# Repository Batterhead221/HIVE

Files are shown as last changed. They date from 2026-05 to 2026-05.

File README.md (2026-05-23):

# HIVE

<p align="center">
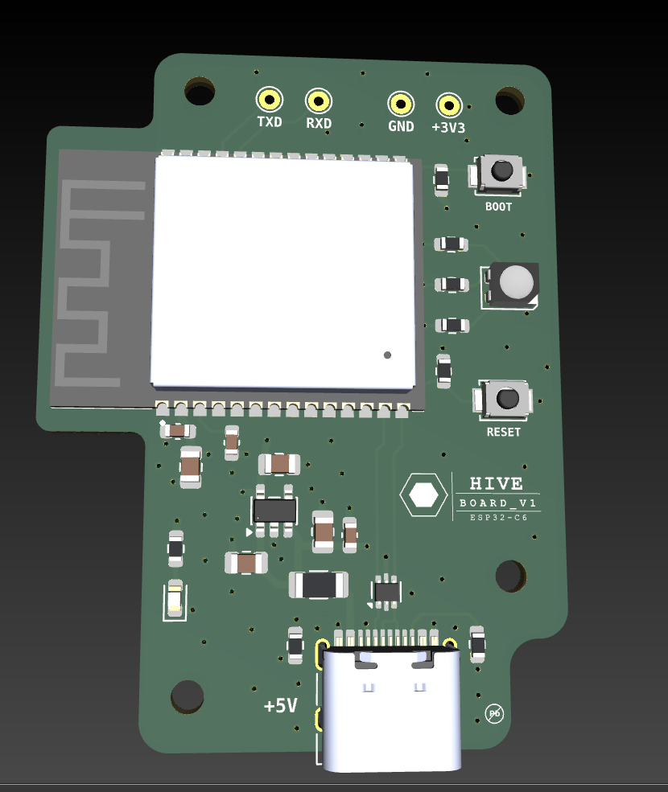
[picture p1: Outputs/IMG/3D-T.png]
HIVE top 3D board render
  
</p>

<p align="center">
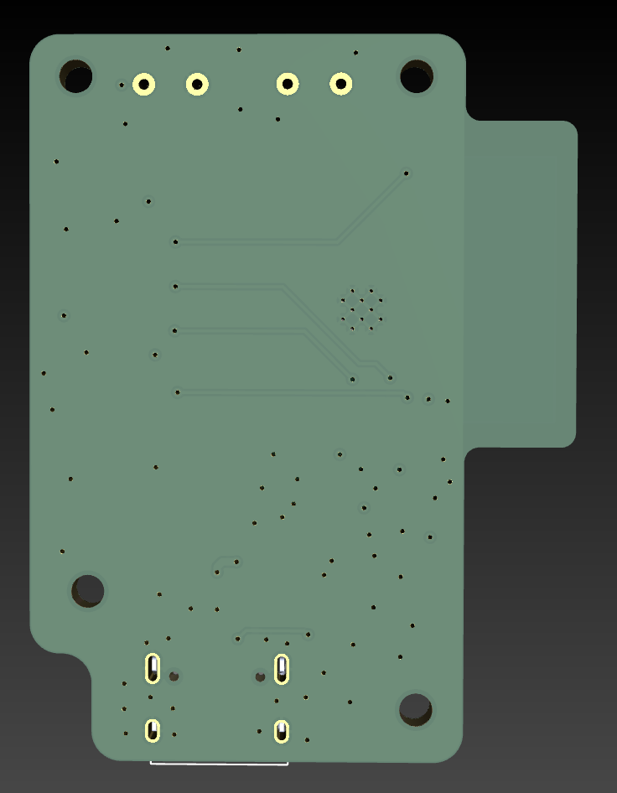
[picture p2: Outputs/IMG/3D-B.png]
HIVE bottom 3D board render
  
</p>

ESP32-C6 gateway board for receiving GRUNT outlet/circuit heartbeat packets.

HIVE is the central receiver in the HIVE + GRUNT monitoring system. It listens for ESP-NOW heartbeat packets from one or more GRUNT sender nodes and reports whether each monitored outlet/circuit is ON, OFF, or waiting for first heartbeat.

## Project Status

Prototype hardware designed. ESP-NOW proof-of-concept tested with an ESP32-C6 gateway and XIAO ESP32-S3 sender node.

## System Role

```text
GRUNT sender node
    ↓ ESP-NOW heartbeat
HIVE gateway board
    ↓ USB serial
Computer / future dashboard
```

## Hardware

Main parts:

- ESP32-C6-WROOM-1-N8 module
- USB-C power and data
- AP2112K-3.3 voltage regulator
- USBLC6-2P6 USB ESD protection
- BOOT and RESET buttons
- RGB status LED
- Power LED
- UART debug pads
- 4-layer PCB with internal GND plane

## Power

HIVE is powered from USB-C VBUS.

```text
USB-C VBUS → fuse/protection → +5V
+5V → AP2112K-3.3 → +3.3V
+3.3V → ESP32-C6-WROOM-1-N8
```

## USB-C

USB-C is used for both power and native ESP32-C6 USB data.

```text
USB D- → ESP32-C6 GPIO12 / USB_D-
USB D+ → ESP32-C6 GPIO13 / USB_D+
CC1 → 5.1k → GND
CC2 → 5.1k → GND
USB shield → GND
```

## Firmware Behavior

HIVE receives heartbeat packets from GRUNT nodes over ESP-NOW.

Each packet contains:

```cpp
typedef struct {
  char nodeId[16];
  uint32_t counter;
  uint32_t uptimeMs;
} HeartbeatPacket;
```

HIVE tracks the last-seen time for each node.

```text
recent heartbeat → node is ON
timeout expired  → node is OFF / missing
never seen       → node is UNKNOWN
```

## PCB Notes

Recommended layer strategy:

```text
T.SIGNAL → components, USB, local signals
GND      → solid internal GND plane
PWR      → +3.3V pour / power routing
B.SIGNAL → GND pour and slow signals
```

Antenna keepout must block copper on all layers:

- No tracks
- No vias
- No pads
- No zone fills
- No components

## Safety Note

HIVE is a low-voltage USB-powered gateway. It does not connect directly to mains voltage.

## Known Notes

- HIVE is the receiver/gateway board.
- GRUNT is the sender/outlet node.
- ESP-NOW devices must be on the same Wi-Fi channel.
- The ESP32-C6 module antenna keepout is critical for reliable wireless performance.
- UART debug pads are included as a backup even though native USB is used.

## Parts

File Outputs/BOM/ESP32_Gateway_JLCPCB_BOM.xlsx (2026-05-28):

Comment | Designator | Footprint
10U | C1,C2,C4,C7 | C_0805_2012Metric
100N | C3,C5,C6 | C_0603_1608Metric
USBLC6-2P6 | D1 | SOT-666
RBG_LED | D2 | LED_Cree-PLCC4_3.2x2.8mm_CCW
GREEN | D3 | LED_0603_1608Metric
1A | F1 | Fuse_1206_3216Metric
USB_C | J1 | USB_C_Receptacle_HRO_TYPE-C-31-M-12
5K1 | R1,R2 | R_0603
10K | R3,R4 | R_0603
1K | R5,R6,R7,R8 | R_0603
ESP32-C6-WROOM-1-N8 | RF1 | XCVR_ESP32-C6-WROOM-1-N8
RESET | SW1 | SW_SPST_B3U-1000P
BOOT | SW2 | SW_SPST_B3U-1000P
AP2112K-3.3 | U1 | SOT-23-5

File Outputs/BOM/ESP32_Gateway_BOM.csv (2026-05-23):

Id | Designator | Footprint | Quantity | Designation | Supplier and ref
1 | C1, C2, C4, C7 | C_0805_2012Metric | 4 | 10U
2 | C3, C5, C6 | C_0603_1608Metric | 3 | 100N
3 | D1 | SOT-666 | 1 | USBLC6-2P6
4 | D2 | LED_Cree-PLCC4_3.2x2.8mm_CCW | 1 | RBG_LED
5 | D3 | LED_0603_1608Metric | 1 | GREEN
6 | F1 | Fuse_1206_3216Metric | 1 | 1A
7 | J1 | USB_C_Receptacle_HRO_TYPE-C-31-M-12 | 1 | USB_C
8 | R1, R2 | R_0603 | 2 | 5K1
9 | R3, R4 | R_0603 | 2 | 10K
10 | R5, R6, R7, R8 | R_0603 | 4 | 1K
11 | RF1 | XCVR_ESP32-C6-WROOM-1-N8 | 1 | ESP32-C6-WROOM-1-N8
12 | SW1 | SW_SPST_B3U-1000P | 1 | RESET
13 | SW2 | SW_SPST_B3U-1000P | 1 | BOOT
14 | TP1 | TestPoint_THTPad_D1.5mm_Drill0.7mm | 1 | TXD
15 | TP2 | TestPoint_THTPad_D1.5mm_Drill0.7mm | 1 | RXD
16 | TP3 | TestPoint_THTPad_D1.5mm_Drill0.7mm | 1 | GND
17 | TP4 | TestPoint_THTPad_D1.5mm_Drill0.7mm | 1 | +3.3V
18 | U1 | SOT-23-5 | 1 | AP2112K-3.3

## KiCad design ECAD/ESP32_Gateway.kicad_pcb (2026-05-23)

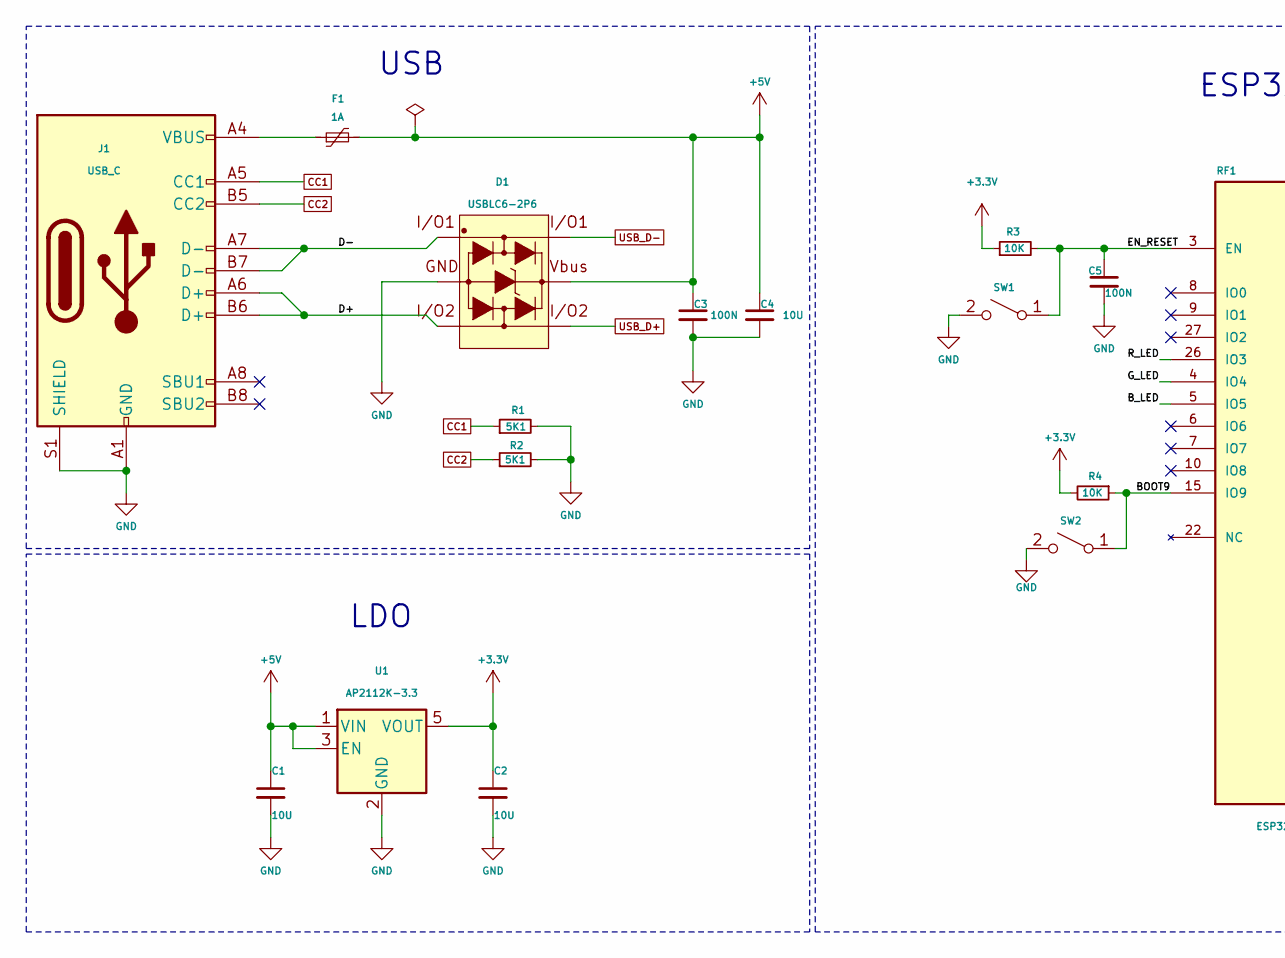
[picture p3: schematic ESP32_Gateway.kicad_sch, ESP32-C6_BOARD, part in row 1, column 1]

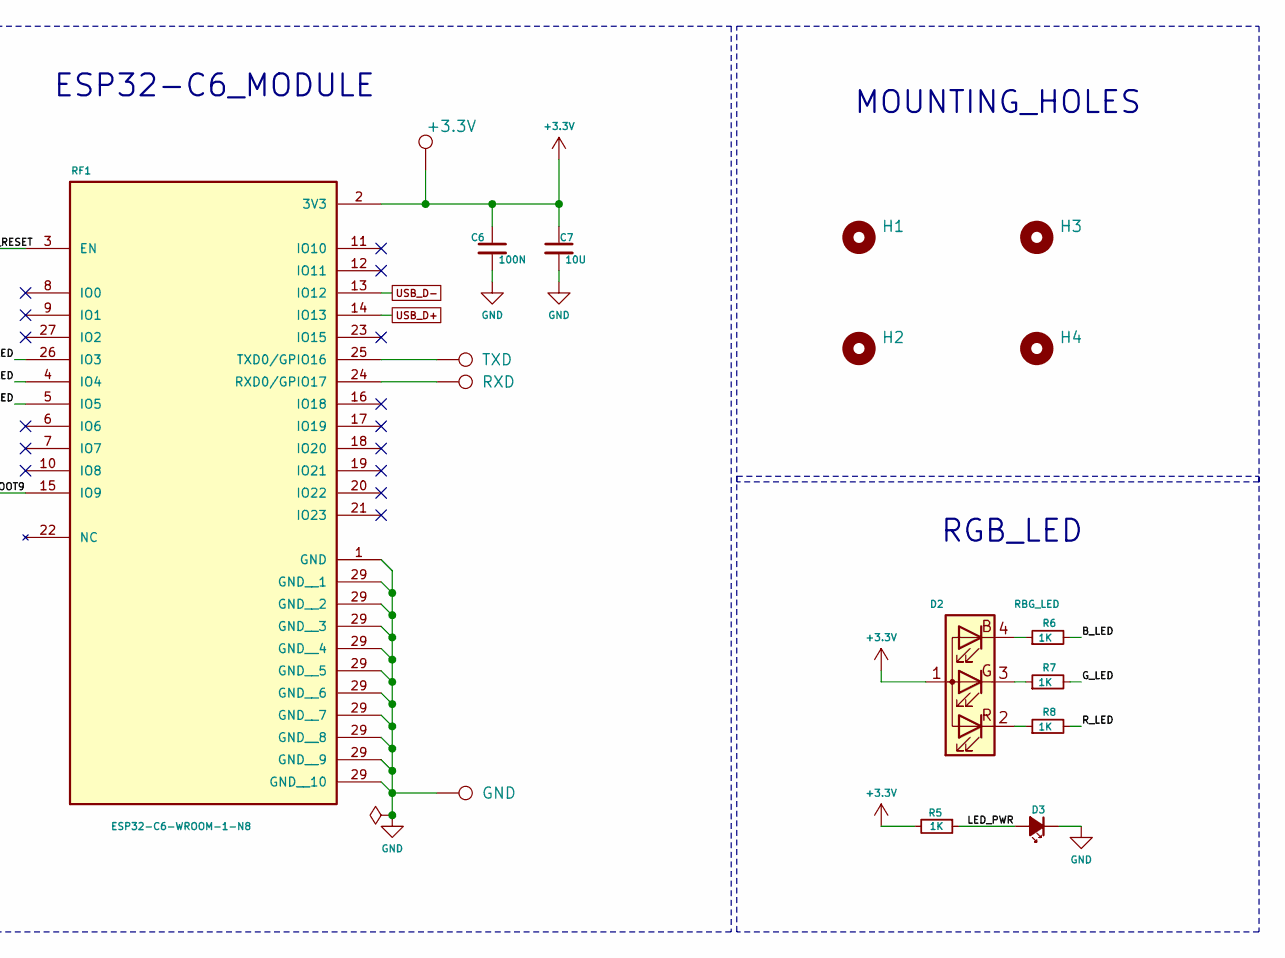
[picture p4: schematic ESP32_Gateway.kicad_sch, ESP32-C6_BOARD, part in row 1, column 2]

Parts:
C1, C2, C4, C7: 10U; C_0805_2012Metric
C3, C5, C6: 100N; C_0603_1608Metric
D1: USBLC6-2P6; SOT-666
D2: RBG_LED; LED_Cree-PLCC4_3.2x2.8mm_CCW
D3: GREEN; LED_0603_1608Metric
F1: 1A; Fuse_1206_3216Metric
H1, H2, H3, H4: MountingHole; MountingHole_2.2mm_M2
J1: USB_C; USB_C_Receptacle_HRO_TYPE-C-31-M-12
R1, R2: 5K1; R_0603
R3, R4: 10K; R_0603
R5, R6, R7, R8: 1K; R_0603
RF1: ESP32-C6-WROOM-1-N8; XCVR_ESP32-C6-WROOM-1-N8; PARTREV 1.0
SW1: RESET; SW_SPST_B3U-1000P
SW2: BOOT; SW_SPST_B3U-1000P
TP1: TXD; TestPoint_THTPad_D1.5mm_Drill0.7mm
TP2: RXD; TestPoint_THTPad_D1.5mm_Drill0.7mm
TP3: GND; TestPoint_THTPad_D1.5mm_Drill0.7mm
TP4: +3.3V; TestPoint_THTPad_D1.5mm_Drill0.7mm
U1: AP2112K-3.3; SOT-23-5

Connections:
+3.3V: C2.1, C6.1, C7.1, D2.1 (A), R3.1, R4.2, R5.2, RF1.2 (3V3), TP4.1 (1_1), U1.5 (VOUT)
+5V: C1.1, C3.1, C4.1, D1.5 (Vbus), F1.2, U1.1 (VIN), U1.3 (EN)
/BOOT9: R4.1, RF1.15 (IO9), SW2.1 (A)
/B_LED: R6.2, RF1.5 (IO5)
/D+: D1.3 (I/O2), J1.A6 (D+), J1.B6 (D+)
/D-: D1.1 (I/O1), J1.A7 (D-), J1.B7 (D-)
/EN_RESET: C5.1, R3.2, RF1.3 (EN), SW1.1 (A)
/G_LED: R7.2, RF1.4 (IO4)
/LED_PWR: D3.2 (A), R5.1
/R_LED: R8.2, RF1.26 (IO3)
CC1: J1.A5 (CC1), R1.1
CC2: J1.B5 (CC2), R2.1
GND: C1.2, C2.2, C3.2, C4.2, C5.2, C6.2, C7.2, D1.2 (GND), D3.1 (K), J1.A1 (GND), J1.A12 (GND), J1.B1 (GND), J1.B12 (GND), J1.S1 (SHIELD), R1.2, R2.2, RF1.1 (GND), RF1.29 (GND__1), SW1.2 (B), SW2.2 (B), TP3.1 (1_1), U1.2 (GND)
unnamed: D2.4 (BK), R6.1
unnamed: D2.3 (GK), R7.1
unnamed: D2.2 (RK), R8.1
unnamed: F1.1, J1.A4 (VBUS), J1.A9 (VBUS), J1.B4 (VBUS), J1.B9 (VBUS)
unnamed: RF1.24 (RXD0/GPIO17), TP2.1 (1_1)
unnamed: RF1.25 (TXD0/GPIO16), TP1.1 (1_1)
USB_D+: D1.4 (I/O2+), RF1.14 (IO13)
USB_D-: D1.6 (I/O1+), RF1.13 (IO12)

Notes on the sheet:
LDO
MOUNTING_HOLES
RGB_LED
ESP32-C6_MODULE
USB

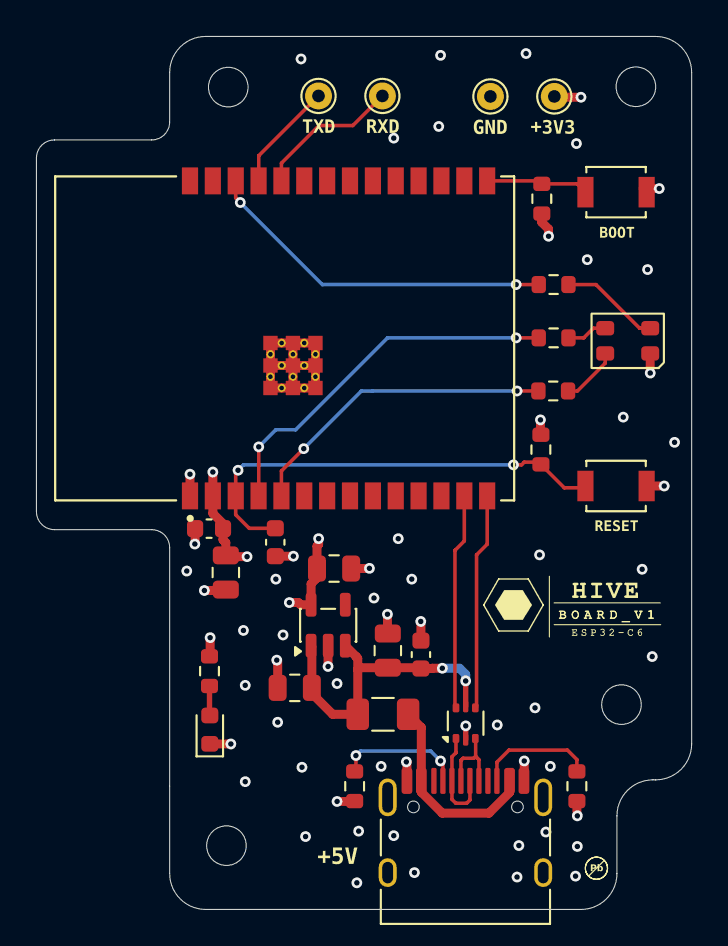
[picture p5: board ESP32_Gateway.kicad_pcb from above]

Board: 4 copper layers, 36.4 x 48.5 mm, 32 parts (0 on the bottom side), 21 nets.

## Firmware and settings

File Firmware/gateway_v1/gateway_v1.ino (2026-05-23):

#include <esp_now.h>
#include <WiFi.h>
#include <esp_wifi.h>

typedef struct {
  char nodeId[16];
  uint32_t counter;
  uint32_t uptimeMs;
} HeartbeatPacket;

HeartbeatPacket incomingPacket;

uint32_t lastSeenMs = 0;
uint32_t lastPrintMs = 0;
bool nodeHasBeenSeen = false;

const uint32_t TIMEOUT_MS = 20000;
const uint32_t PRINT_MS = 2000;

void onReceive(const esp_now_recv_info_t *info, const uint8_t *data, int len) {
  Serial.print("RX packet len=");
  Serial.println(len);

  if (len == sizeof(HeartbeatPacket)) {
    memcpy(&incomingPacket, data, sizeof(incomingPacket));

    lastSeenMs = millis();
    nodeHasBeenSeen = true;

    Serial.print("Heartbeat from ");
    Serial.print(incomingPacket.nodeId);
    Serial.print(" | count=");
    Serial.print(incomingPacket.counter);
    Serial.print(" | uptime=");
    Serial.println(incomingPacket.uptimeMs);
  }
}

void setup() {
  Serial.begin(115200);
  delay(1000);

  Serial.println();
  Serial.println("=== ESP32-C6 GATEWAY RECEIVER ===");

  WiFi.mode(WIFI_STA);
  delay(200);
  WiFi.disconnect(false);
  delay(200);

  esp_wifi_set_protocol(
    WIFI_IF_STA,
    WIFI_PROTOCOL_11B | WIFI_PROTOCOL_11G | WIFI_PROTOCOL_11N
  );

  esp_wifi_set_channel(1, WIFI_SECOND_CHAN_NONE);

  Serial.print("Gateway MAC: ");
  Serial.println(WiFi.macAddress());

  uint8_t channel;
  wifi_second_chan_t second;
  esp_wifi_get_channel(&channel, &second);
  Serial.print("Gateway channel: ");
  Serial.println(channel);

  if (esp_now_init() != ESP_OK) {
    Serial.println("ESP-NOW init failed");
    return;
  }

  esp_now_register_recv_cb(onReceive);

  Serial.println("Gateway started");
}

void loop() {
  if (millis() - lastPrintMs >= PRINT_MS) {
    lastPrintMs = millis();

    if (!nodeHasBeenSeen) {
      Serial.println("NODE_01 = UNKNOWN / waiting for first heartbeat");
    } else {
      uint32_t age = millis() - lastSeenMs;

      if (age < TIMEOUT_MS) {
        Serial.print(incomingPacket.nodeId);
        Serial.print(" = ON | last seen ");
        Serial.print(age);
        Serial.println(" ms ago");
      } else {
        Serial.print(incomingPacket.nodeId);
        Serial.print(" = OFF / missing | last seen ");
        Serial.print(age);
        Serial.println(" ms ago");
      }
    }
  }
}
